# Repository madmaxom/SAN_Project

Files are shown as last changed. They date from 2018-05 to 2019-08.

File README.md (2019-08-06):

<p align="center">
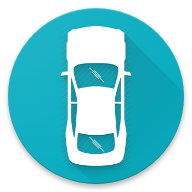
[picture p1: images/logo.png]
  
</p>

---

# Park Assistant for RC-Car

The idea of this project is, to build a parking aid system for a small RC car. Parking aids are advanced driver assistance systems designed to make parking easier. Such systems monitor an area of between roughly 20 and 180 cm in front of and behind the vehicle and warn the driver about any obstacles. 

Furthermore, sharp changes in the acceleration which indicates emergency brakes shall be detected and shown via led indication. An additional feature is the automatic light which turns on, when it gets dark and dizzy. Also, the temperature is measured, which could be used to overwatch the battery temp of the RC car. After capturing the sensor data by our board, it gets send to a smartphone app which visualizes the data. 

The distance sensors for the actual parking procedure have been implemented with ultrasonic sensors. However, the detailed hardware description can be found in the following sections. 

## Hardware
The picture below shows the complete circuit of the complete experiment. For the obstacle detection multiple ultrasonic sensors have been used whereby three were placed in the back and one in the front of the car. Furthermore, as already mentioned, the acceleration is recorded in order to react to emergency breaks. The piezo signalizes obstacles in the way and adjust its sound based on the distance to the respective objects. The light sensor is used in order to automatically activate the lights of the car. The bluetooth module connects to the Android application to visualize the data sensed. 

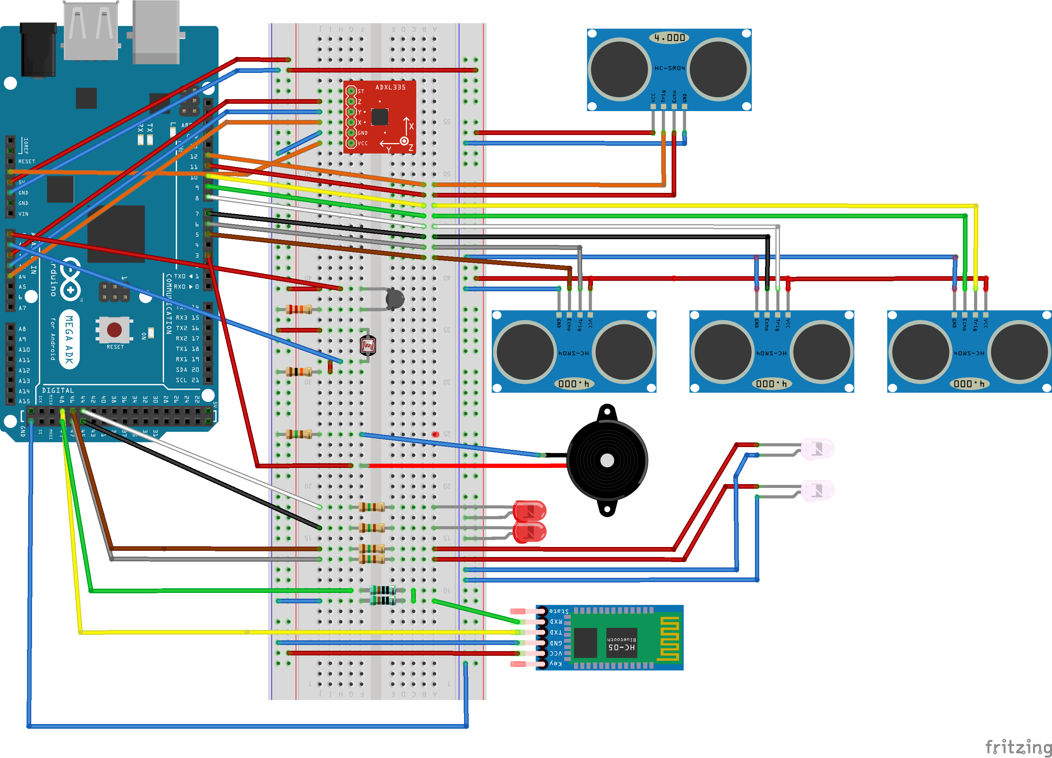
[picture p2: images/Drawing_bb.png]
Hardware


## Implementation 
For starting up the sensors/Arduino, just connect the USB cable to a USB port with 5V, 1A output.  The Arduino now is in an idle state and waits for the Bluetooth module to be connected to a respective device via the provided android application. After successfully connecting, the main routine starts. In this routine, Arduino threads  are started which handle basically all sensor in “parallel”. This Library helps to maintain organized and to facilitate the use of multiple tasks. We can use Timers Interrupts, and make it powerful, running "pseudo-background" tasks under the rug. 

While the read sensor values are updated in the background, the Bluetooth sending routine is handled in the loop method. For sending data, data are kept in packages with start and stop byte, command byte and separators. Therefore, it is easier for the android application to parse the data and visualize them. 

### Arduino Threads
As mentioned above, the states are run in “pseudo” parallelism and therefore the UML state chart looks like this. The states front, back, back_r and back_l describes the ultrasonic sensors. The sensor values are fetched in these states. The piezo state checks permanently if an obstacle is to close to the RC car and signalizes the distance via varying sounds. The Watchdog permanently checks the Bluetooth connection and resets the board if no response is received from the android application. The sending routine basically just formats all the data into packages and passes them to the Bluetooth module.  

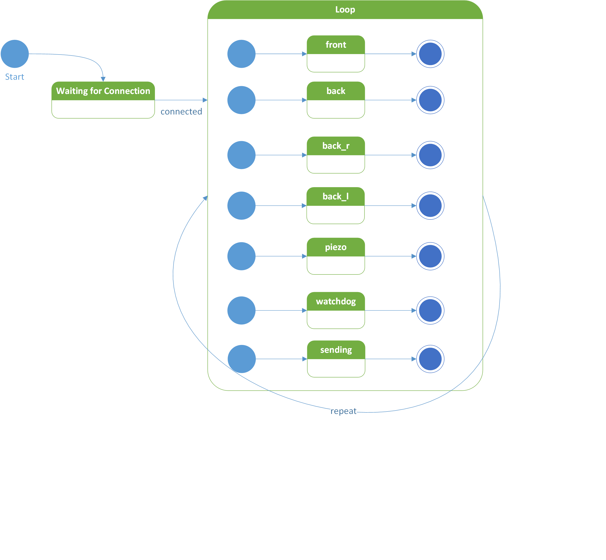
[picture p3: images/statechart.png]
Placement


### Protocol 

To send data over Bluetooth, an Android client has been used on the other side of communication. The android app receives the data and tries to parse them. In every message, a command is specified to signalize how the data should be parsed. 

The protocol looks as follows: 

-	Start Byte “$”
-	Command Byte “[1-5]:”
-	Separator “;”
-	Data 
-	End Byte “*”
---
If the message is received and parsed correctly, the Android application answers with ACK otherwise with NACK. 
-	ACK “|”
-	NACK “?”

## Android Application

<p align="center">
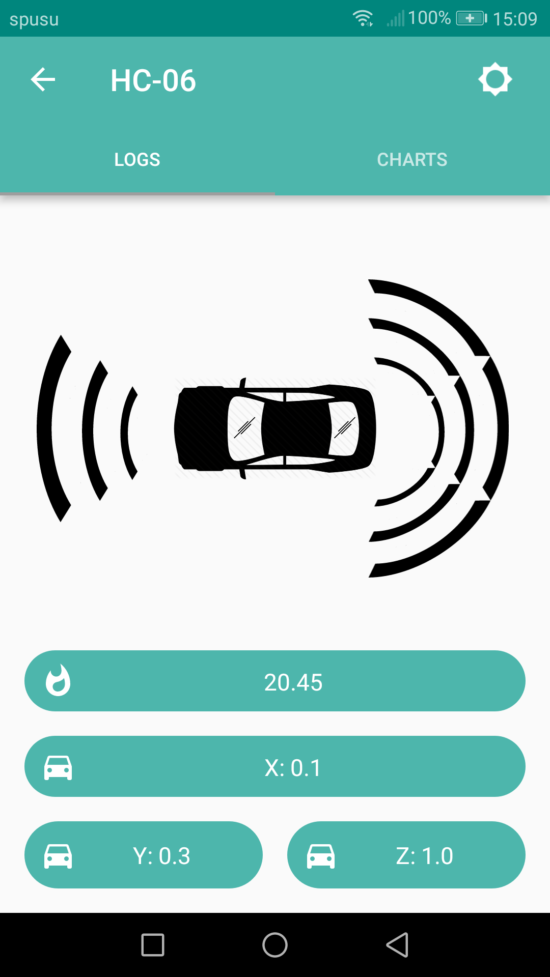
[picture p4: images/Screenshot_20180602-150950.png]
  
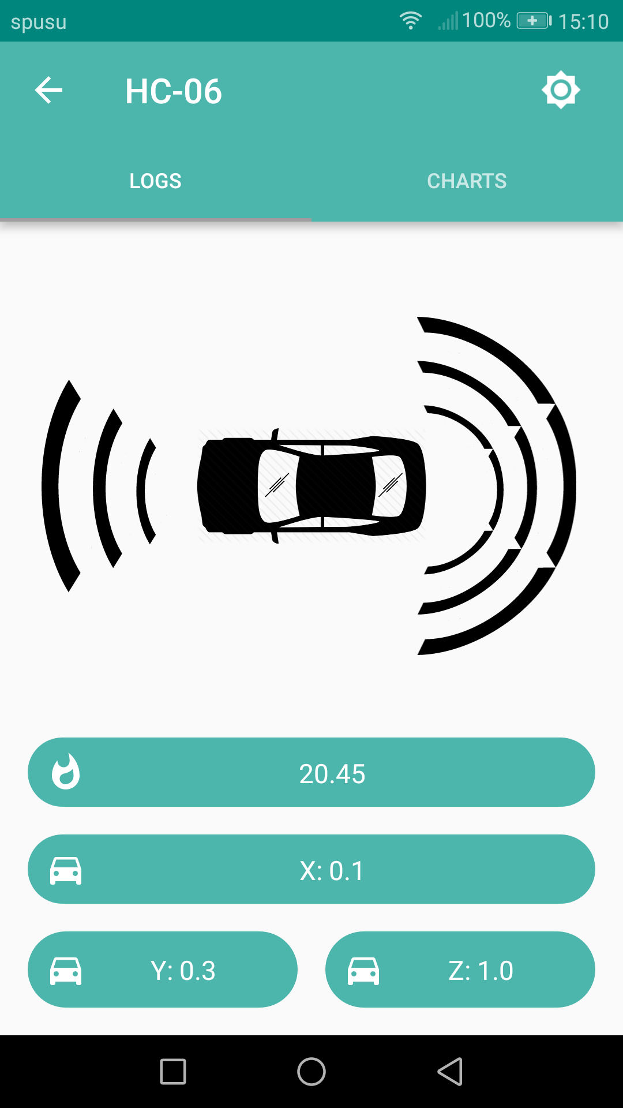
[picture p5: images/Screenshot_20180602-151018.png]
  
</p>

<p align="center">
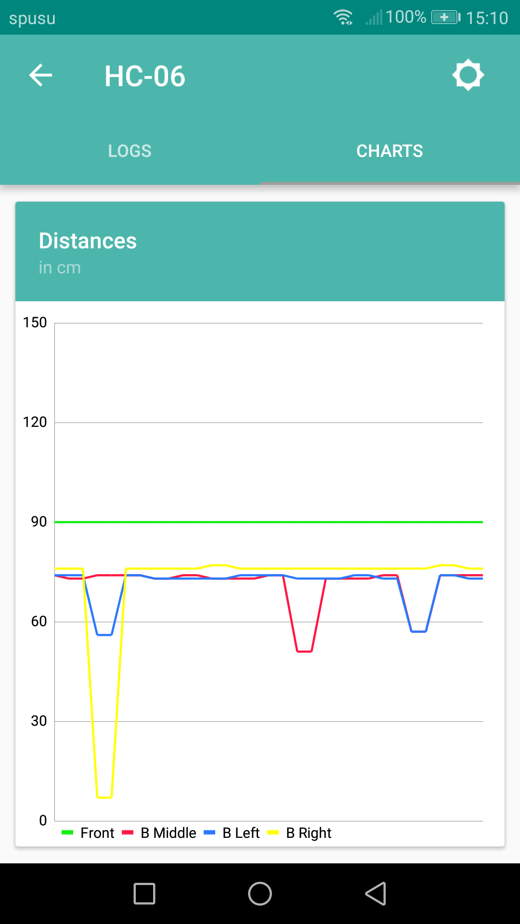
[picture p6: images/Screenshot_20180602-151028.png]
  
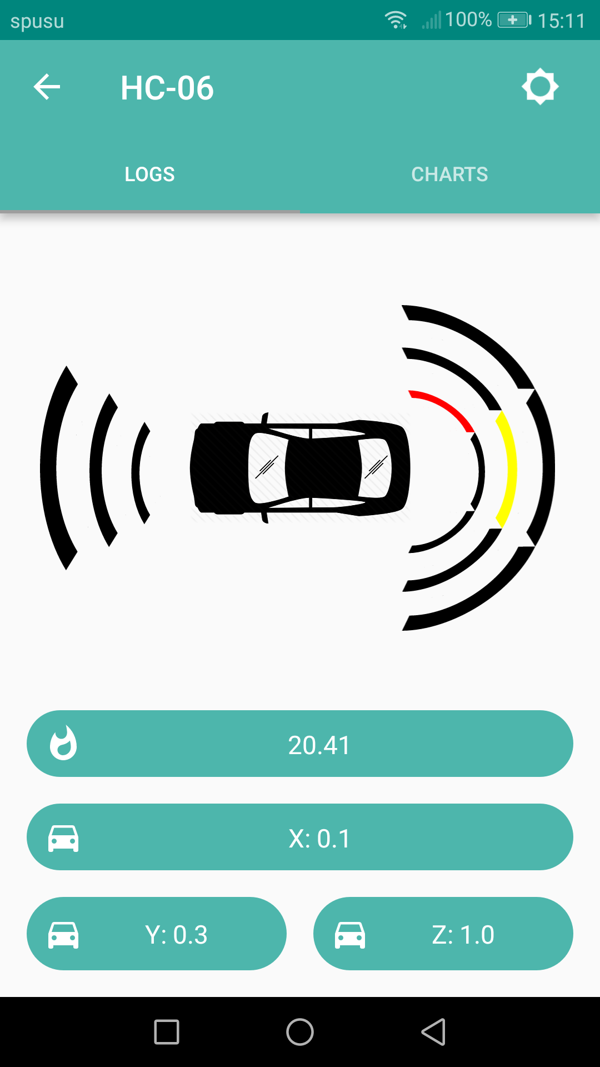
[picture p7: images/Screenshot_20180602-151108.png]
  
</p>

## RC-Car 

<p align="center">
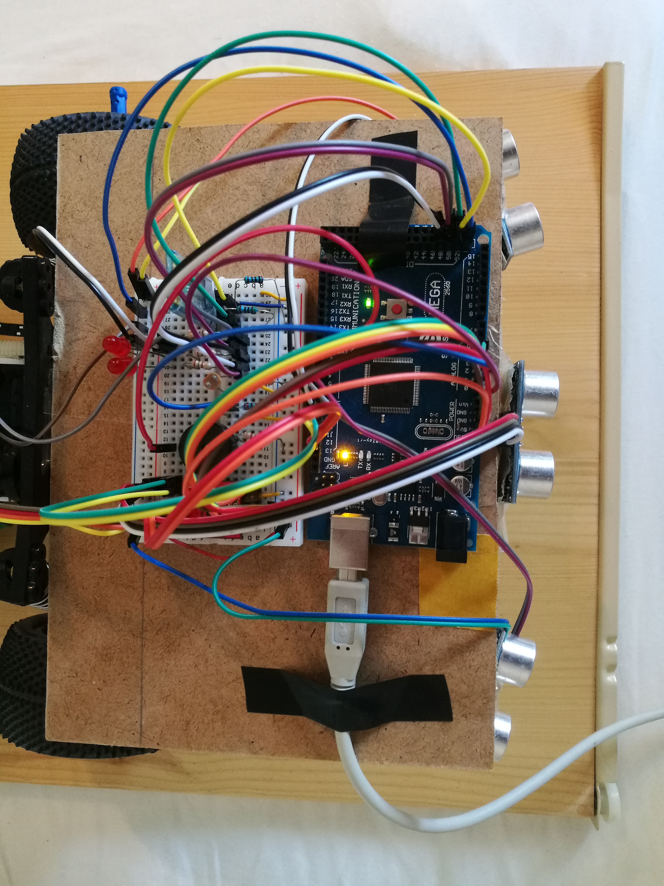
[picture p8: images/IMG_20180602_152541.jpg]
  
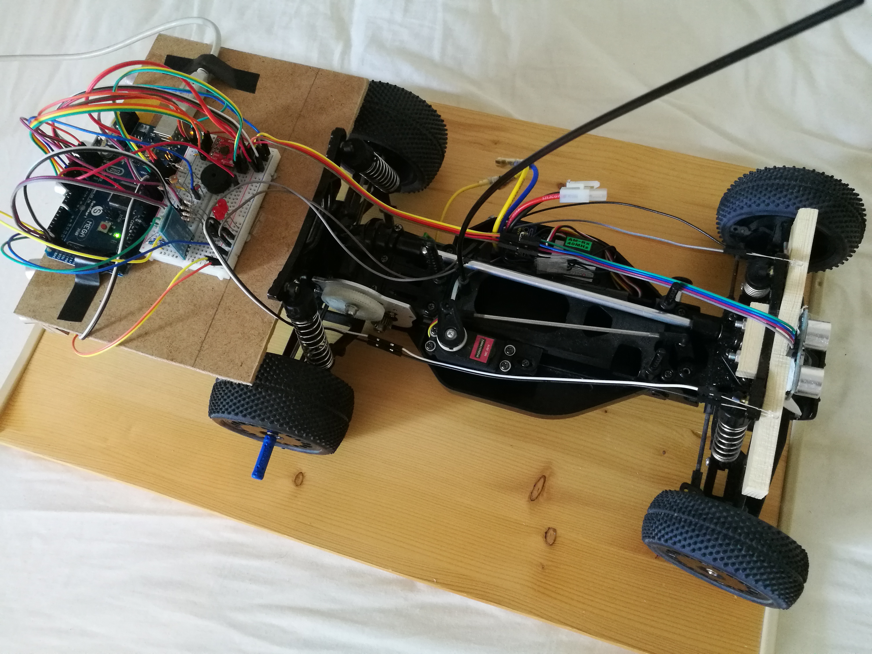
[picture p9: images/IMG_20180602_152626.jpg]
  
</p>

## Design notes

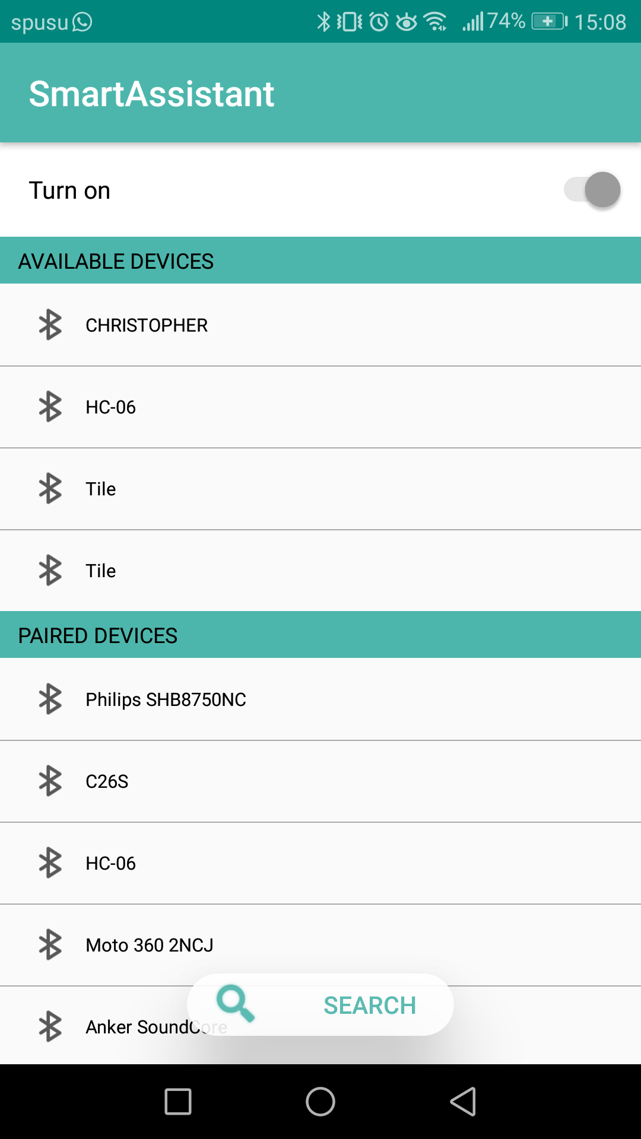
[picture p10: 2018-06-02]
images/Screenshot_20180602-150811.png

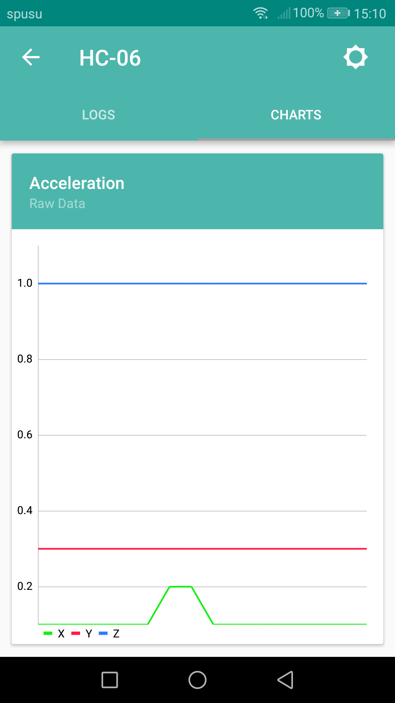
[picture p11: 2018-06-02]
images/Screenshot_20180602-151034.png

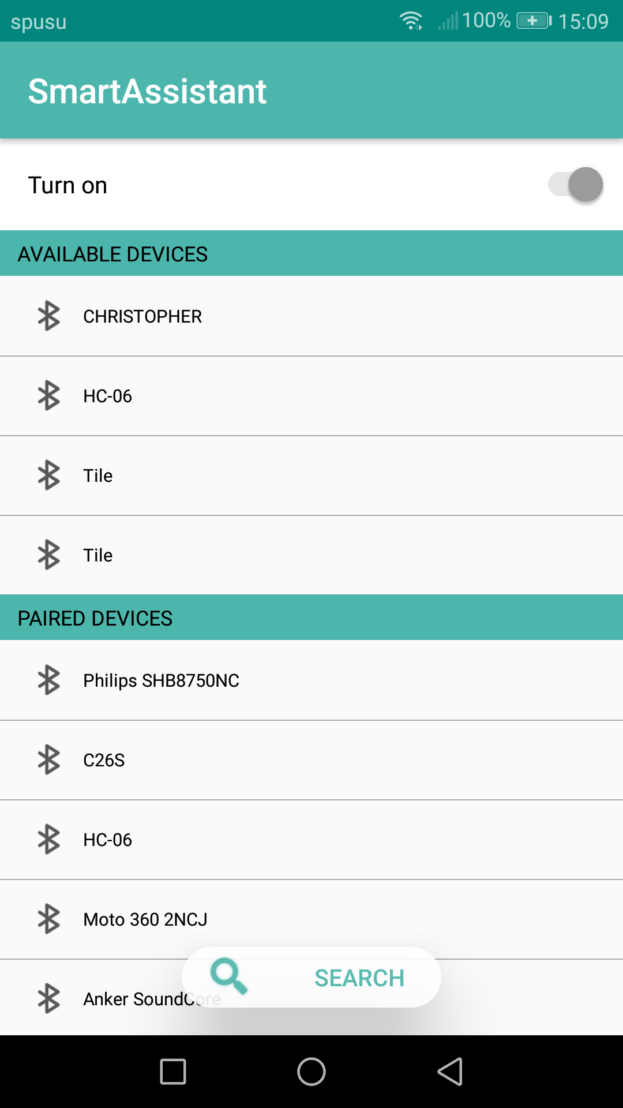
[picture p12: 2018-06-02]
images/Screenshot_20180602-150920.png

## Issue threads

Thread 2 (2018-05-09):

Light sensor

madmaxom, 2018-05-09:
conversion of light adc values to lumen!?
day driving light - just front lights activated (possibly dimmed)
turning on/off(= just dimmed) lights
night mode - full power on lights (possible with pwm)

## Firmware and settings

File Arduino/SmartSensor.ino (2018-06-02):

#include <SoftwareSerial.h>
#include "LdrDriver.h"
#include "MessageBuilder.h"
#include "BluetoothDriver.h"
#include <ThreadController.h>
#include <Thread.h>
#include <StaticThreadController.h>
#include "TemperatureDriver.h"
#include "AccelerometerDriver.h"
#include <avr/wdt.h>

#pragma region FIELDS
TemperatureDriver temperature_driver;
AccelerometerDriver accelerometer_driver;
BluetoothDriver bluetooth_driver;
MessageBuilder message_builder;
LdrDriver ldr_driver;

ThreadController thread_controller = ThreadController();
Thread tfront = Thread();
Thread tback_m = Thread();
Thread tback_l = Thread();
Thread tback_r = Thread();
Thread tPiezo = Thread();
Thread tBacklight = Thread();
Thread tTimeOut = Thread();

double gdata[3];
double recent_g = 0;

int distance_front = 150;
int distance_back_m = 150;
int distance_back_l = 150;
int distance_back_r = 150;

int sendCounter = 0;

const int distance_3 = 30;
const int distance_2 = 15;
const int distance_1 = 5;
#pragma endregion

#pragma region PIN DEFINITIONS
const int PIN_X = A4;
const int PIN_Y = A3;
const int PIN_Z = A2;

const int PIN_LDR = A0;
const int PIN_TEMP = A1;

const int PIN_FRONTLIGHT_LEFT = 50;
const int PIN_FRONTLIGHT_RIGHT = 51;

const int PIN_BACKLIGHT_LEFT = 48;
const int PIN_BACKLIGHT_RIGHT = 49;

const int PIN_BT_RX = 52;
const int PIN_BT_TX = 53;

const int PIN_DISTANCE_FRONT_TRIG = 12;
const int PIN_DISTANCE_FRONT_ECHO = 11;

const int PIN_DISTANCE_BACK_M_TRIG = 10;
const int PIN_DISTANCE_BACK_M_ECHO = 9;

const int PIN_DISTANCE_BACK_L_TRIG = 8;
const int PIN_DISTANCE_BACK_L_ECHO = 7;

const int PIN_DISTANCE_BACK_R_TRIG = 6;
const int PIN_DISTANCE_BACK_R_ECHO = 5;

const int PIN_PIEZO = 2;
#pragma endregion

#pragma region METHOD SIGNATURES
unsigned long string_to_hex(const String& string);
unsigned long hex_to_string(const String& string);

void handleMessage();
void sendData();
void turnLightsOn();
void dimLights();
void ldr();
void ultrasonicFront();
void ultrasonicBackM();
void ultrasonicBackL();
void ultrasonicBackR();
void checkPiezo();
void turnBacklightOn();
void checkTimeOut();
#pragma endregion

void setup()
{
	Serial.begin(9600);

	temperature_driver = TemperatureDriver(PIN_TEMP);
	accelerometer_driver = AccelerometerDriver(PIN_X, PIN_Y, PIN_Z, 1);
	bluetooth_driver = BluetoothDriver(PIN_BT_RX, PIN_BT_TX);
	ldr_driver = LdrDriver(PIN_LDR);
	message_builder = MessageBuilder();

	// Pin Modes Leds
	pinMode(PIN_FRONTLIGHT_LEFT, OUTPUT);
	pinMode(PIN_FRONTLIGHT_RIGHT, OUTPUT);
	pinMode(PIN_BACKLIGHT_LEFT, OUTPUT);
	pinMode(PIN_BACKLIGHT_RIGHT, OUTPUT);

	// Pin Modes Ultrasonic
	pinMode(PIN_DISTANCE_FRONT_TRIG, OUTPUT);
	pinMode(PIN_DISTANCE_FRONT_ECHO, INPUT);

	pinMode(PIN_DISTANCE_BACK_M_TRIG, OUTPUT);
	pinMode(PIN_DISTANCE_BACK_M_ECHO, INPUT);

	pinMode(PIN_DISTANCE_BACK_L_TRIG, OUTPUT);
	pinMode(PIN_DISTANCE_BACK_L_ECHO, INPUT);

	pinMode(PIN_DISTANCE_BACK_R_TRIG, OUTPUT);
	pinMode(PIN_DISTANCE_BACK_R_ECHO, INPUT);

	// Threads
	tfront.onRun(ultrasonicFront);
	tfront.setInterval(1);
	tback_m.onRun(ultrasonicBackM);
	tback_m.setInterval(1);
	tback_r.onRun(ultrasonicBackR);
	tback_r.setInterval(1);
	tback_l.onRun(ultrasonicBackL);
	tback_l.setInterval(1);
	tPiezo.onRun(checkPiezo);
	tPiezo.setInterval(40);

	tTimeOut.onRun(checkTimeOut);
	tTimeOut.setInterval(400);

	tBacklight.onRun(turnBacklightOn);
	tBacklight.setInterval(20);

	thread_controller.add(&tfront);
	thread_controller.add(&tback_m);
	thread_controller.add(&tback_l);
	thread_controller.add(&tback_r);
	thread_controller.add(&tPiezo);
	thread_controller.add(&tTimeOut);
}

void loop()
{
	if (bluetooth_driver.IsConnected() != true)
	{
		bluetooth_driver.Connect();
	}
	else
	{
		if (thread_controller.shouldRun())
		{
			thread_controller.run();
		}
		sendData();
	}
}


void sendData()
{
	char response[20];
	// ACC ***************************************************
	accelerometer_driver.GetGData(gdata);
	message_builder.BuildResponse(
		String(*gdata, 1) + SEPERATOR + String(*(gdata + 1), 1) + SEPERATOR + String(*(gdata + 2), 1), ACC_COMMAND, response);
	Serial.println(response);
	bluetooth_driver.Send(response);

	if (fabs(recent_g - *(gdata + 1)) > 0.5)
	{
		if (tBacklight.shouldRun())
		{
			tBacklight.run();
		}
	}
	recent_g = *(gdata + 1);

	// TEMP **************************************************
	if (sendCounter > 15)
	{
		const auto temp = temperature_driver.GetTemperature();
		message_builder.BuildResponse(String(temp, 2), TEMP_COMMAND, response);
		Serial.println(response);
		bluetooth_driver.Send(response);

		// LDR ***************************************************
		ldr();

		sendCounter = 0;
	}

	// DISTANCE **********************************************
	message_builder.BuildResponse(
		String(distance_front) + SEPERATOR + String(distance_back_m) + SEPERATOR + String(distance_back_l) +
		SEPERATOR + String(distance_back_r), DIST_COMMAND, response);
	Serial.println(response);
	bluetooth_driver.Send(response);

	sendCounter++;
}

void turnBacklightOn()
{
	digitalWrite(PIN_BACKLIGHT_LEFT, HIGH);
	digitalWrite(PIN_BACKLIGHT_RIGHT, HIGH);
	delay(2000);
	digitalWrite(PIN_BACKLIGHT_LEFT, LOW);
	digitalWrite(PIN_BACKLIGHT_RIGHT, LOW);
}

void checkPiezo()
{
	if (distance_front < distance_3 && distance_front > distance_2
		|| distance_back_l < distance_3 && distance_back_l > distance_2
		|| distance_back_m < distance_3 && distance_back_m > distance_2
		|| distance_back_r < distance_3 && distance_back_r > distance_2)
	{
		analogWrite(PIN_PIEZO, 50);
		delay(200);
		analogWrite(PIN_PIEZO, 0);
		delay(200);
	}
	else if (distance_front < distance_2 && distance_front > distance_1
		|| distance_back_l < distance_2 && distance_back_l > distance_1
		|| distance_back_m < distance_2 && distance_back_m > distance_1
		|| distance_back_r < distance_2 && distance_back_r > distance_1)
	{
		analogWrite(PIN_PIEZO, 50);
		delay(100);
		analogWrite(PIN_PIEZO, 0);
		delay(100);
	}
	else if (distance_front < distance_1 && distance_front > 0
		|| (distance_back_l < distance_1 && distance_back_l > 0)
		|| (distance_back_m < distance_1 && distance_back_m > 0)
		|| (distance_back_r < distance_1 && distance_back_r > 0))
	{
		analogWrite(PIN_PIEZO, 50);
	}
	else
	{
		analogWrite(PIN_PIEZO, 0);
	}
}

void checkTimeOut()
{
	wdt_enable(WDTO_2S);
	if (bluetooth_driver.Receive())
	{
		wdt_reset();
	}
}

void ldr()
{
	char response[20];
	const auto ldr_reading = ldr_driver.GetValue();
	if (ldr_reading < 600)
	{
		dimLights();
		message_builder.BuildResponse(String(1), LDR_COMMAND, response);
		Serial.println(response);
		bluetooth_driver.Send(response);
	}
	else
	{
		turnLightsOn();
		message_builder.BuildResponse(String(0), LDR_COMMAND, response);
		Serial.println(response);
		bluetooth_driver.Send(response);
	}
}


void ultrasonicFront()
{
	digitalWrite(PIN_DISTANCE_FRONT_TRIG, LOW);
	delayMicroseconds(5);
	// Sets the trigPin on HIGH state for 10 micro seconds
	digitalWrite(PIN_DISTANCE_FRONT_TRIG, HIGH);
	delayMicroseconds(10);
	digitalWrite(PIN_DISTANCE_FRONT_TRIG, LOW);
	// Reads the echoPin, returns the sound wave travel time in microseconds
	const int duration = pulseIn(PIN_DISTANCE_FRONT_ECHO, HIGH);
	const int distance = duration / 2 / 29.1;
	if (distance >= 0 && distance <= 150)
	{
		distance_front = distance;
	}
}

void ultrasonicBackM()
{
	digitalWrite(PIN_DISTANCE_BACK_M_TRIG, LOW);
	delayMicroseconds(5);
	// Sets the trigPin on HIGH state for 10 micro seconds
	digitalWrite(PIN_DISTANCE_BACK_M_TRIG, HIGH);
	delayMicroseconds(10);
	digitalWrite(PIN_DISTANCE_BACK_M_TRIG, LOW);
	// Reads the echoPin, returns the sound wave travel time in microseconds
	const int duration = pulseIn(PIN_DISTANCE_BACK_M_ECHO, HIGH);
	const int distance = duration / 2 / 29.1;
	if (distance >= 0 && distance <= 150)
	{
		distance_back_m = distance;
	}
}

void ultrasonicBackL()
{
	digitalWrite(PIN_DISTANCE_BACK_L_TRIG, LOW);
	delayMicroseconds(5);
	// Sets the trigPin on HIGH state for 10 micro seconds
	digitalWrite(PIN_DISTANCE_BACK_L_TRIG, HIGH);
	delayMicroseconds(10);
	digitalWrite(PIN_DISTANCE_BACK_L_TRIG, LOW);
	// Reads the echoPin, returns the sound wave travel time in microseconds
	const int duration = pulseIn(PIN_DISTANCE_BACK_L_ECHO, HIGH);
	const int distance = duration / 2 / 29.1;
	if (distance >= 0 && distance <= 150)
	{
		distance_back_l = distance;
	}
}

void ultrasonicBackR()
{
	digitalWrite(PIN_DISTANCE_BACK_R_TRIG, LOW);
	delayMicroseconds(5);
	// Sets the trigPin on HIGH state for 10 micro seconds
	digitalWrite(PIN_DISTANCE_BACK_R_TRIG, HIGH);
	delayMicroseconds(10);
	digitalWrite(PIN_DISTANCE_BACK_R_TRIG, LOW);
	// Reads the echoPin, returns the sound wave travel time in microseconds
	const int duration = pulseIn(PIN_DISTANCE_BACK_R_ECHO, HIGH);
	const int distance = duration / 2 / 29.1;
	if (distance >= 0 && distance <= 150)
	{
		distance_back_r = distance;
	}
}

void turnLightsOn()
{
	digitalWrite(PIN_FRONTLIGHT_LEFT, HIGH);
	digitalWrite(PIN_FRONTLIGHT_RIGHT, HIGH);
}

void dimLights()
{
	digitalWrite(PIN_FRONTLIGHT_LEFT, LOW);
	digitalWrite(PIN_FRONTLIGHT_RIGHT, LOW);
}


unsigned long string_to_hex(const String& string)
{
	return strtoul(string.c_str(), nullptr, 16);
}

unsigned long hex_to_string(const String& string)
{
	return strtoul(string.c_str(), nullptr, 16);
}

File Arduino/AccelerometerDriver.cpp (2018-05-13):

// 
// 
// 

#include "AccelerometerDriver.h"


AccelerometerDriver::AccelerometerDriver()
{
	maxAcc = 1;
	pinX = 0;
	pinY = 1;
	pinZ = 2;
	Calibrate();
	ResetMaxValues();
}

AccelerometerDriver::~AccelerometerDriver()
= default;

AccelerometerDriver::AccelerometerDriver(const int x, const int y, const int z, const double max)
{
	maxAcc = max;
	pinX = x;
	pinY = y;
	pinZ = z;
	Calibrate();
	ResetMaxValues();
}

void AccelerometerDriver::GetRawData(double* values) const
{
	values[0] = GetRawX();
	values[1] = GetRawY();
	values[2] = GetRawZ();
}

double AccelerometerDriver::GetRawX() const
{
	return analogRead(pinX);
}

double AccelerometerDriver::GetRawY() const
{
	return analogRead(pinY);
}

double AccelerometerDriver::GetRawZ() const
{
	return analogRead(pinZ);
}

void AccelerometerDriver::GetVoltageData(double* values) const
{
	values[0] = GetVoltageX();
	values[1] = GetVoltageY();
	values[2] = GetVoltageZ();
}

double AccelerometerDriver::GetVoltageX() const
{
	const auto x = GetRawX();
	return x * 3.3 / 1024;
}

double AccelerometerDriver::GetVoltageY() const
{
	const auto y = GetRawY();
	return y * 3.3 / 1024;
}

double AccelerometerDriver::GetVoltageZ() const
{
	const auto z = GetRawZ();
	return z * 3.3 / 1024;
}

void AccelerometerDriver::GetGData(double* values)
{
	values[0] = GetGX();
	values[1] = GetGY();
	values[2] = GetGZ();
}

double AccelerometerDriver::GetGX()
{
	double valueX = 0;
	for (auto i = 0; i < 10; i++)
	{
		valueX += GetRawX();
	}
	valueX = valueX / 10;

	auto val = map(valueX, xMin, xMax, -1000, 1000) / 1000.0;
	if (abs(val) > absMaxX)
	{
		absMaxX = fabs(val);
	}
	return val;
}

double AccelerometerDriver::GetGY()
{
	double valueY = 0;
	for (auto i = 0; i < 10; i++)
	{
		valueY += GetRawY();
	}
	valueY = valueY / 10;

	auto val = map(valueY, yMin, yMax, -1000, 1000) / 1000.0;
	if (abs(val) > absMaxY)
	{
		absMaxY = fabs(val);
	}
	return val;
}

double AccelerometerDriver::GetGZ()
{
	double valueZ = 0;
	for (auto i = 0; i < 10; i++)
	{
		valueZ += GetRawZ();
	}
	valueZ = valueZ / 10;
	auto val = map(valueZ, zMin, zMax, -1000, 1000) / 1000.0;
	if (abs(val) > absMaxZ)
	{
		absMaxZ = fabs(val);
	}
	return val;
}

void AccelerometerDriver::Calibrate()
{
	xMin = 265;
	xMax = 398;

	yMin = 259;
	yMax = 393;

	zMin = 281;
	zMax = 413;

//	xMin = (valueX * 3.3 / 1024 - 0.3) * 1024 / 3.3;
//	xMax = (valueX * 3.3 / 1024 + 0.3) * 1024 / 3.3;
//	yMin = (valueY * 3.3 / 1024 - 0.3) * 1024 / 3.3;
//	yMax = (valueY * 3.3 / 1024 + 0.3) * 1024 / 3.3;
//	zMin = (valueZ * 3.3 / 1024 - 0.3) * 1024 / 3.3;
//	zMax = (valueZ * 3.3 / 1024 + 0.3) * 1024 / 3.3;
}

void AccelerometerDriver::ResetMaxValues()
{
	absMaxX = 0;
	absMaxY = 0;
	absMaxZ = 0;
}

void AccelerometerDriver::GetMaxValues(double* values) const
{
	values[0] = GetMaxValueX();
	values[1] = GetMaxValueY();
	values[2] = GetMaxValueZ();
}

double AccelerometerDriver::GetMaxValueX() const
{
	return absMaxX;
}

double AccelerometerDriver::GetMaxValueY() const
{
	return absMaxY;
}

double AccelerometerDriver::GetMaxValueZ() const
{
	return absMaxZ;
}

void AccelerometerDriver::GetTilt(double* values)
{
	const float alpha = 0.5;

	auto Xg = GetGX();
	auto Yg = GetGY();
	auto Zg = GetGZ();

	fXg = Xg * alpha + (fXg * (1.0 - alpha));
	fYg = Yg * alpha + (fYg * (1.0 - alpha));
	fZg = Zg * alpha + (fZg * (1.0 - alpha));

	//Roll & Pitch Equations
	const auto roll = (atan2(-fYg, fZg) * 180.0) / M_PI;
	const auto pitch = (atan2(fXg, sqrt(fYg * fYg + fZg * fZg)) * 180.0) / M_PI;

	values[0] = roll;
	values[1] = pitch;
}

bool AccelerometerDriver::Alarm()
{
	auto max = sqrt(pow(GetGX(), 2) + pow(GetGY(), 2) + pow(GetGX(), 2));
//	Serial.print(max);
	return max > maxAcc;
}

void AccelerometerDriver::SetMax(long max)
{
	this->maxAcc = max; 
}

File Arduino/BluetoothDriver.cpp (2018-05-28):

// 
// 
// 

#include "BluetoothDriver.h"


BluetoothDriver::BluetoothDriver() : serial(12, 13)
{
	inputString.reserve(200);
}

BluetoothDriver::BluetoothDriver(int rx, int tx) : serial(rx, tx)
{
	inputString.reserve(200);
}

BluetoothDriver::~BluetoothDriver()
{
}

bool BluetoothDriver::IsConnected()
{
	return connected;
}

void BluetoothDriver::Disconnect()
{
	serial.end();
}

void BluetoothDriver::Connect()
{
	serial.begin(9600);
	serial.setTimeout(25);
	while (connected == false)
	{
		if (serial.available() > 0)
		{
			inputString = serial.readStringUntil('*');
			if (inputString.indexOf(START_COMMUNICATION) > 0)
			{
				serial.write(START_COMMUNICATION);
				connected = true;
			}
		}
	}
}

void BluetoothDriver::Send(const String& msg)
{
	serial.write(msg.c_str());
	// while (true)
	// {
	// 	if (serial.available() > 0) {
	// 		inputString = serial.readString();
	// 		Serial.println(inputString);
	// 		if (inputString.indexOf(ACK) >= 0)
	// 		{
	// 			break;
	// 		}
	// 	}
	// }
}

bool BluetoothDriver::Receive()
{
	if (serial.available() > 0)
	{
		inputString = serial.readString();
		Serial.println(inputString);
		if (inputString.indexOf(ACK) >= 0)
		{
			return true;
		}
	}
	return false;
}

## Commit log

2018-05-14 bluetooth communication, arduino sending, arduino ldr, android parser
2018-05-23 added speeddriver and led on off
2018-05-23 leds front
2018-05-23 added backlight led switching ignored _vm/ folders
2018-05-26 arduino mega setup, ultrasonic sensors, lights
2018-06-05 added thread lib
